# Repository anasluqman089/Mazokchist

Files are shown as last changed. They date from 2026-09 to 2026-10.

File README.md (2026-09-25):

# Mazokchist



*Hello Everyone!*

What is Mazokchist you might ask? it is a small environmental monitor built around the Seeed XIAO ESP32-C6. A BME680
sensor measures temperature, humidity, pressure and gas resistance and sends
the readings over I2C to the XIAO, which displays them on a Waveshare 2.9"
e-Paper screen.

Why the name is Mazokchist? It is just a msde up name no need to know the meaning.

## How it works

- **BME680** — reads temperature, humidity, pressure and gas resistance, and
  sends the data to the XIAO over I2C.
- **XIAO ESP32-C6** — reads the sensor over I2C and drives the display over SPI.
- **Waveshare 2.9" e-Paper** — shows the latest readings. The screen refreshes
  once a minute.

## Bill of Materials

| Qty | Component | Category | Price (USD) | Buy Link | Notes |
| --: | --- | --- | ---: | --- | --- |
| 1 | Seeed XIAO ESP32-C6 | Electronics | $5.20 | [Seeed Studio](https://www.seeedstudio.com/Seeed-Studio-XIAO-ESP32C6-p-5884.html) | MCU |
| 1 | BME680 Breakout Module | Electronics | $13.99 | [Amazon](https://www.amazon.com/HiLetgo-Temperature-Precision-Environmental-Monitoring/dp/B0CDWXZNY7) | Enviromental Sensor |
| 1 | Waveshare 2.9 inch E-Paper Module V2 SSD1680 | Electronics | $21.99 | [Waveshare](https://www.waveshare.com/product/displays/e-paper/2.9inch-e-paper-module.htm) | 296×128 monochrome e-paper display |
| 1 | JST PH 2.0mm 8-Pin SMT Header | Electronics | ~$1.00 | — | For the PCB |
| 1 | JST PH 2.0mm 8-Pin Cable | Electronics | ~$2.00 | — | Connecting the PCB to the display |
| 4 | M3 × 20mm Screw | Hardware | ~$2.00 | — | Securing the PCB |
| 4 | M3 × 6mm Screw | Hardware | ~$2.00 | — | Securing the case |
| 4 | M3 Standoff | Hardware | ~$1.00 | — | PCB/display spacers |
| 1 | 3D Printed Enclosure | Mechanical  | ~$5.00 | — | PLA or PETG enclosure |

## Estimated Total

**≈ $56.18 USD**

> Prices are approximate and may vary depending on seller, quantity, shipping, taxes, and promotions.

Check the mounting hole diameter on your PCB before ordering screws — M3 is assumed here but confirm it matches your board.

## Wiring

| BME680 | XIAO pin |
|---|---|
| VCC | 3V3 |
| GND | GND |
| SDA | D4 |
| SCL | D5 |
| SDO | GND |
| CS | 3V3 |

| e-Paper (J1) | XIAO pin |
|---|---|
| VCC | 3V3 |
| GND | GND |
| DIN | D10 |
| CLK | D8 |
| CS | D3 |
| DC | D2 |
| RST | D1 |
| BUSY | D0 |

**Notice** : BME680 SDO tied to GND sets its I2C address to 0x76. BME680 CS tied to 3V3
forces the module into I2C mode.

## How to Build

### 1. Assemble the hardware and firmware
1. Fabricate the PCB from the KiCad project (or wire the parts manually on protoboard using the wiring table above).
2. Solder the XIAO ESP32-C6, the BME680 module (directly onto its PCB pads — no cable needed), and the JST PH 2.0mm 8-pin SMT header onto the board.
3. Connect the Waveshare 2.9" e-Paper display to the JST PH header using the JST PH 2.0mm cable.
4. Mount the board using the 4 mounting holes, M3 screws, standoffs and nuts.
5. Use Arduino IDE and download all the libraries
6. Upload the code
7. *Power it on!*

## Images

### Schematic



### PCB



### CAD





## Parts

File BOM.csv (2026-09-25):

Qty | Component | Category | Price ($) | Buy_Link | Notes
1 | Seeed XIAO ESP32-C6 | Electronics | $5.20 | https://www.seeedstudio.com/Seeed-Studio-XIAO-ESP32C6-p-5884.html | MCU
1 | BME680 Breakout Module | Electronics | $13.99 | https://www.amazon.com/HiLetgo-Temperature-Precision-Environmental-Monitoring/dp/B0CDWXZNY7 | Enciromental sensor
1 | Waveshare 2.9 inch E-Paper Module V2 SSD1680 | Electronics | $21.99 | https://www.waveshare.com/product/displays/e-paper/2.9inch-e-paper-module.htm | 296x128 monochrome e-paper display
1 | JST PH 2.0mm 8-Pin SMT Header | Electronics | ~$1.00 | - | For the PCB
1 | JST PH 2.0mm 8-Pin Cable | Electronics | ~$2.00 | - | Connecting the PCB to the display
4 | M3 x 20mm Screw | Hardware | ~$2.00 | - | Securing the PCB
4 | M3 x 6mm Screw | Hardware | ~$2.00 | - | Securing the case
4 | M3 Standoff | Hardware | ~$1.00 | - | PCB/display spacers
1 | 3D Printed Enclosure | Mechanical | ~$5.00 | - | PLA or PETG enclosure

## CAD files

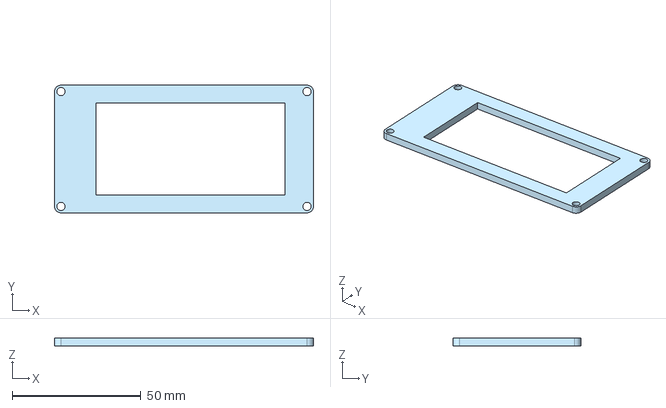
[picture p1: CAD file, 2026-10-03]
CAD/Mazokchist Lid.step
100.4 x 49.5 x 3.00 mm

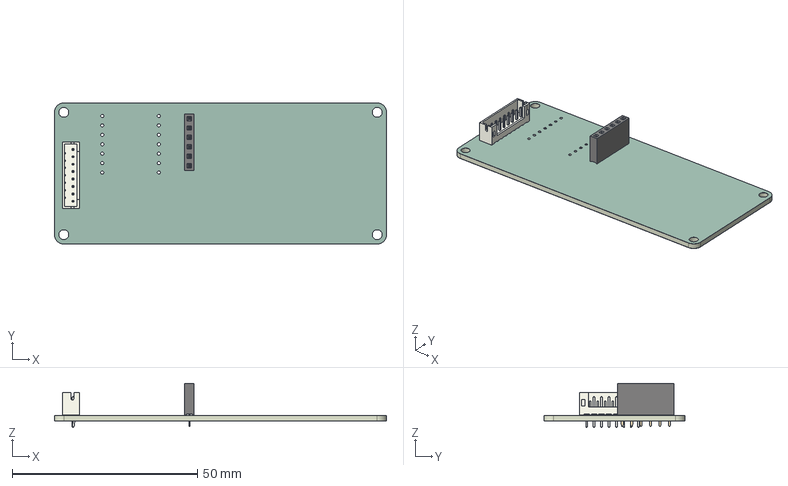
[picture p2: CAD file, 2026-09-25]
PCB/Mazokchist_PCB.step
89.5 x 38.0 x 11.9 mm
PinSocket_1x06_P2.54mm_Vertical
JST_B8B_PH_K
Maz4324_soldermask x 2
Maz4324_PCB

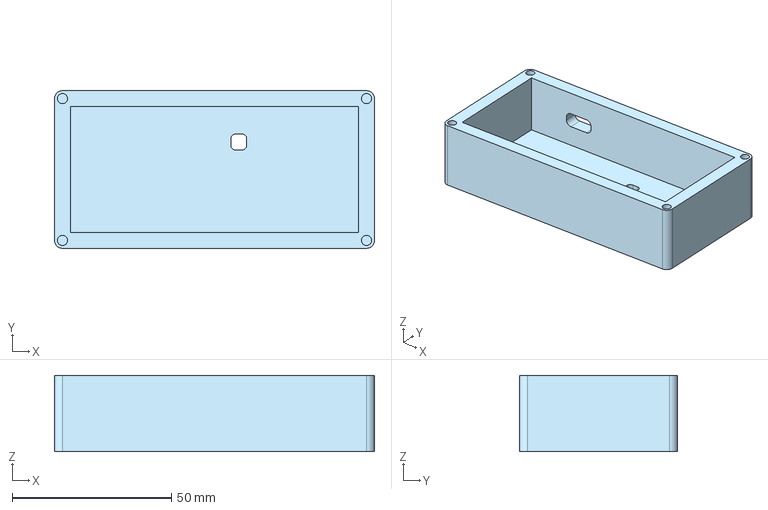
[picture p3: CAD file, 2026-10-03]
CAD/Mazokchist Case.step
100.4 x 49.5 x 24.0 mm

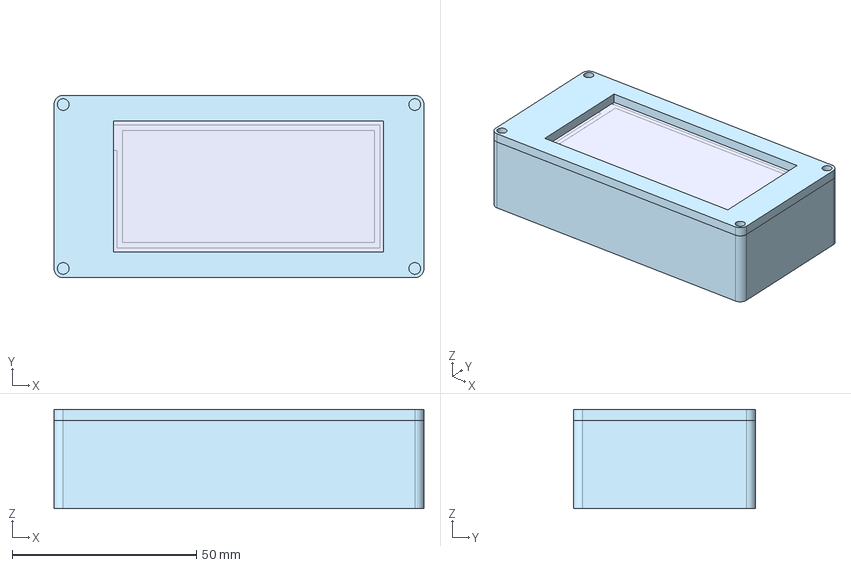
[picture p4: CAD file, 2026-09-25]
CAD/Mazokchist_CAD.step
100.4 x 49.5 x 27.0 mm
CUT-EXTRUDE5:1__Body1
U.FL Connector v1:1__Body1
CHAMFER9:1__Body1
8 Legs SMD Component, CJMCU-680, BME680 Ambient Temperature, Relative Humidity, Barometric Pressure, and Gas VOC Sensor
BOSS-EXTRUDE14_9_:1__Body1
BOSS-EXTRUDE14_7_:1__Body1
SMD Capacitor, Configurable, CJMCU-680, BME680 Ambient Temperature, R elative Humidity, Barometric Pressure, and Gas VOC Sensor(C3) x 3
3.3V LDO Regulator, CJMCU-680, BME680 Ambient Temperature, Relative H umidity, Barometric Pressure, and Gas VOC Sensor x 2
Shield:1__Body1
U.FL Connector v1:1__Body2
BOSS-EXTRUDE14_4_:1__Body1
BOSS-EXTRUDE7_3_:1__Body1
SKTAAAE010 v1:1__Body1_1
SMD Capacitor, Configurable, CJMCU-680, BME680 Ambient Temperature, R elative Humidity, Barometric Pressure, and Gas VOC Sensor(C1) x 3
BOSS-EXTRUDE14_6_:1__Body1
U.FL Connector v1:1__Body3
philips screw[3]
Seeed Studio XIAO-ESP32-C6:1__PCB (1)
philips screw[2]
Sensor Module, CJMCU-680, BME680 Ambient Temperature, Relative Humidi ty, Barometric Pressure, and Gas VOC Sensor
SMD Capacitor, Configurable, CJMCU-680, BME680 Ambient Temperature, R elative Humidity, Barometric Pressure, and Gas VOC Sensor(C2) x 3
hex standoffs[4]
SKTAAAE010 v1:1__Body1
Seeed Studio XIAO-ESP32-C6:1__Pad (1)
KH5220-A36 (Ceramic Antenna) v2:1__Body4
1.65mm connector housing
PCB, CJMCU-680, BME680 Ambient Temperature, Relative Humidity, Barome tric Pressure, and Gas VOC Sensor
Seeed Studio XIAO-ESP32-C6:1__Pad
SMD Resistor, Configurable, CJMCU-680, BME680 Ambient Temperature, Re lative Humidity, Barometric Pressure, and Gas VOC Sensor(R1) x 3
pcb
flex connector
BOSS-EXTRUDE14_10_:1__Body1
BOSS-EXTRUDE7_1_:1__Body1
SMD Resistor, Configurable, CJMCU-680, BME680 Ambient Temperature, Re lative Humidity, Barometric Pressure, and Gas VOC Sensor(R2) x 3
BOSS-EXTRUDE7_2_:1__Body1
Level Signal Conversion Chip, CJMCU-680, BME680 Ambient Temperature, Relative Humidity, Barometric Pressure, and Gas VOC Sensor
philips screw[4]
BOSS-EXTRUDE7_6_:1__Body1
philips screw
display body
BOSS-EXTRUDE14_2_:1__Body1
BOSS-EXTRUDE14_3_:1__Body1
hex standoffs[1]
BOSS-EXTRUDE14_1_:1__Body1
BOSS-EXTRUDE14_12_:1__Body1
hex standoffs[3]
BOSS-EXTRUDE14_8_:1__Body1
flex connector body
BOSS-EXTRUDE7_8_:1__Body1
BOSS-EXTRUDE7_4_:1__Body1
BOSS-EXTRUDE7_7_:1__Body1
BOSS-EXTRUDE14_11_:1__Body1
hex standoffs[2]
KH5220-A36 (Ceramic Antenna) v2:1__Body2
JST_B8B_PH_K
assorted electronic components
KH5220-A36 (Ceramic Antenna) v2:1__Body1
MIRROR2:1__Body1
BOSS-EXTRUDE7_5_:1__Body1
BOSS-EXTRUDE7_9_:1__Body1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

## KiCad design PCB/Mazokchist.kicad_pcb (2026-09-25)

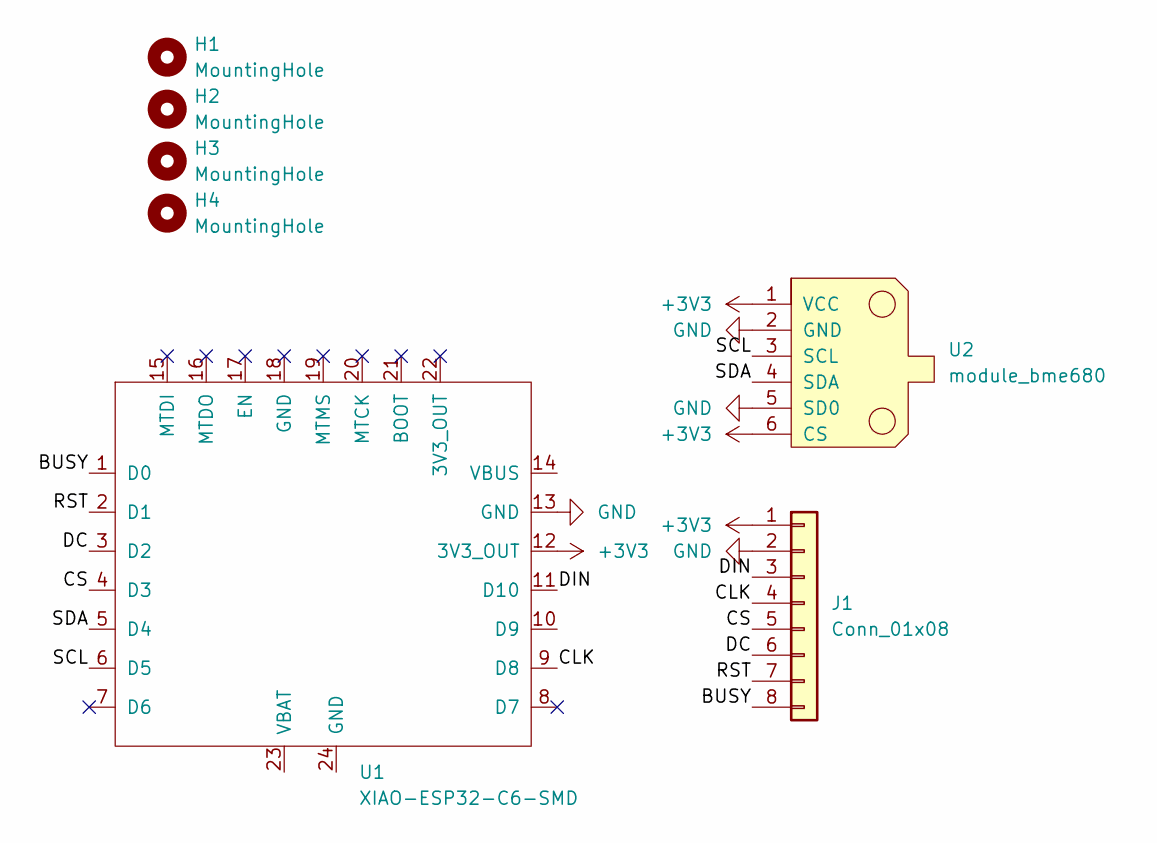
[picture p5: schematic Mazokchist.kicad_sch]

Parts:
H1, H2, H3, H4: MountingHole; MountingHole_2.7mm_M2.5
J1: Conn_01x08; JST_PH_B8B-PH-K_1x08_P2.00mm_Vertical
U1: XIAO-ESP32-C6-SMD; XIAO-ESP32-C6-DIP
U2: module_bme680

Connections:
+3V3: J1.1, U1.12 (3V3_OUT), U2.1 (VCC), U2.6 (CS)
/BUSY: J1.8, U1.1 (D0)
/CLK: J1.4, U1.9 (D8)
/CS: J1.5, U1.4 (D3)
/DC: J1.6, U1.3 (D2)
/DIN: J1.3, U1.11 (D10)
/RST: J1.7, U1.2 (D1)
/SCL: U1.6 (D5), U2.3 (SCL)
/SDA: U1.5 (D4), U2.4 (SDA)
GND: J1.2, U1.13 (GND), U2.2 (GND), U2.5 (SD0)

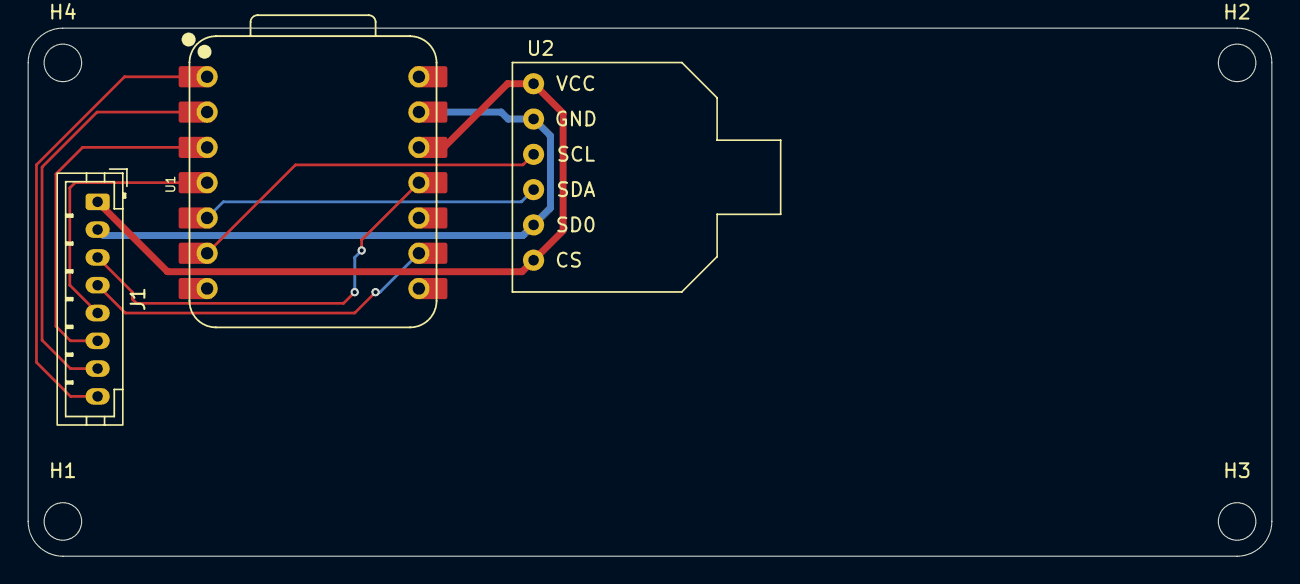
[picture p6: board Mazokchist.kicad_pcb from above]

Board: 2 copper layers, 89.5 x 38.0 mm, 7 parts (0 on the bottom side), 10 nets.

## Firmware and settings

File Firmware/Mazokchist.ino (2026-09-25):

// Library

#include <SPI.h>
#include <Wire.h>
#include <Adafruit_Sensor.h>
#include <Adafruit_BME680.h>
#include <GxEPD2_BW.h>
#include <Fonts/FreeMonoBold9pt7b.h>
#include <Fonts/FreeMonoBold12pt7b.h>

// Pin
#define PIN_BUSY  D0
#define PIN_RST   D1
#define PIN_DC    D2
#define PIN_CS    D3
#define PIN_SDA   D4
#define PIN_SCL   D5
#define PIN_SCK   D8
#define PIN_MISO  D9   
#define PIN_MOSI  D10

// BME680 I2C address: SDO is tied to GND on this board so the address is 0x76
#define BME680_ADDR_PRIMARY   0x76
#define BME680_ADDR_SECONDARY 0x77

// Display
// Waveshare 2.9" V2 (SSD1680, 128x296):
GxEPD2_BW<GxEPD2_290_T94_V2, GxEPD2_290_T94_V2::HEIGHT> display(
    GxEPD2_290_T94_V2(PIN_CS, PIN_DC, PIN_RST, PIN_BUSY));

// Sensor
Adafruit_BME680 bme;

// Keep this fairly long
const unsigned long UPDATE_INTERVAL_MS = 60000UL; // 60 seconds
unsigned long lastUpdate = 0;

void setup() {
  Serial.begin(115200);
  delay(200);

  // I2C bus for the BME680
  Wire.begin(PIN_SDA, PIN_SCL);

  // SPI bus for the e-paper (remap ESP32 hardware SPI pins)
  SPI.begin(PIN_SCK, PIN_MISO, PIN_MOSI, PIN_CS);

  // Init BME680, trying both common I2C addresses
  if (!bme.begin(BME680_ADDR_PRIMARY) && !bme.begin(BME680_ADDR_SECONDARY)) {
    Serial.println("BME680 not found - check wiring/I2C address!");
    while (true) delay(1000);
  }

  // Recommended oversampling / filter settings (from Adafruit examples)
  bme.setTemperatureOversampling(BME680_OS_8X);
  bme.setHumidityOversampling(BME680_OS_2X);
  bme.setPressureOversampling(BME680_OS_4X);
  bme.setIIRFilterSize(BME680_FILTER_SIZE_3);
  bme.setGasHeater(320, 150); // 320 degC for 150 ms

  // Init e-paper
  display.init(115200);
  display.setRotation(1);        // landscape, 296 x 128
  display.setTextColor(GxEPD_BLACK);

  updateDisplay(); // show a first reading immediately
  lastUpdate = millis();
}

void loop() {
  if (millis() - lastUpdate >= UPDATE_INTERVAL_MS) {
    lastUpdate = millis();
    updateDisplay();
  }
}

void updateDisplay() {
  if (!bme.performReading()) {
    Serial.println("Failed to read BME680");
    return;
  }

  float temperature = bme.temperature;              // deg C
  float humidity    = bme.humidity;                 // %RH
  float pressure    = bme.pressure / 100.0F;         // hPa
  float gas         = bme.gas_resistance / 1000.0F;  // kOhm

  Serial.printf("T=%.1fC  H=%.1f%%  P=%.1fhPa  Gas=%.1fkOhm\n",
                temperature, humidity, pressure, gas);

  char tempStr[16], humStr[16], presStr[16], gasStr[16];
  snprintf(tempStr, sizeof(tempStr), "%.1f C",   temperature);
  snprintf(humStr,  sizeof(humStr),  "%.1f %%",  humidity);
  snprintf(presStr, sizeof(presStr), "%.1f hPa", pressure);
  snprintf(gasStr,  sizeof(gasStr),  "%.1f kOhm", gas);

  display.setFullWindow();
  display.firstPage();
  do {
    display.fillScreen(GxEPD_WHITE);

    display.setFont(&FreeMonoBold12pt7b);
    display.setCursor(8, 20);
    display.print("BME680 Sensor");
    display.drawFastHLine(8, 26, display.width() - 16, GxEPD_BLACK);

    display.setFont(&FreeMonoBold9pt7b);

    display.setCursor(8, 50);
    display.print("Temp:  ");
    display.print(tempStr);

    display.setCursor(8, 70);
    display.print("Hum:   ");
    display.print(humStr);

    display.setCursor(8, 90);
    display.print("Press: ");
    display.print(presStr);

    display.setCursor(8, 110);
    display.print("Gas:   ");
    display.print(gasStr);

  } while (display.nextPage());

  display.hibernate(); // low power until next update
}

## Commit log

2026-09-25 Update README with project details and assembly instructions
    Added detailed project description, components list, wiring instructions, and assembly steps.
2026-09-25 Add BOM.csv with components and hardware details
    [BOM.csv]
2026-09-25 Correct wording for Waveshare e-Paper display entry
    Updated the description of the Waveshare e-Paper display to correct the wording.
    [BOM.csv]
2026-09-25 Update BOM.csv to simplify component descriptions
    Removed unnecessary details from component notes.
    [BOM.csv]
2026-09-25 Revise Mazokchist.csv with new component entries
    Updated component list with detailed descriptions and categories.
    [Mazokchist.csv]
2026-09-25 Refactor Mazokchist.csv by removing 'Store' column
    Removed the 'Store' column and adjusted the CSV format.
    [Mazokchist.csv]
2026-09-25 Revise component list with store and price updates
    Updated component details, added store information, and corrected item descriptions.
    [Mazokchist.csv]
2026-09-25 Remove 'Store' column from Mazokchist.csv
    Removed 'Store' column from the inventory CSV.
    [Mazokchist.csv]
2026-09-25 Revise component details and pricing in Mazokchist.csv
    Updated prices and links for several components, changed currency format from USD to $.
    [Mazokchist.csv]
2026-09-25 Revise components list in Mazokchist.csv
    Updated quantities and corrected formatting in the components list.
    [Mazokchist.csv]
2026-09-25 Revise BOM.csv component details
    Updated component descriptions for clarity and consistency.
    [BOM.csv, Mazokchist.csv]
2026-09-25 Update README with Bill of Materials and pricing
    Added a Bill of Materials section with detailed components and pricing.
2026-09-25 Update README with images and additional sections
    Added images and sections for schematic, PCB, and CAD.
2026-10-03 Added separate file for the CAD
    [Mazokchist Case.step, Mazokchist Lid.step]
